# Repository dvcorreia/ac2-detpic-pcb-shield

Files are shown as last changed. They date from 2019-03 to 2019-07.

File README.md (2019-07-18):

<p align="center">This repository contains hardware designs for a PCB shield that extends the detpic32 development board created at DETI UA

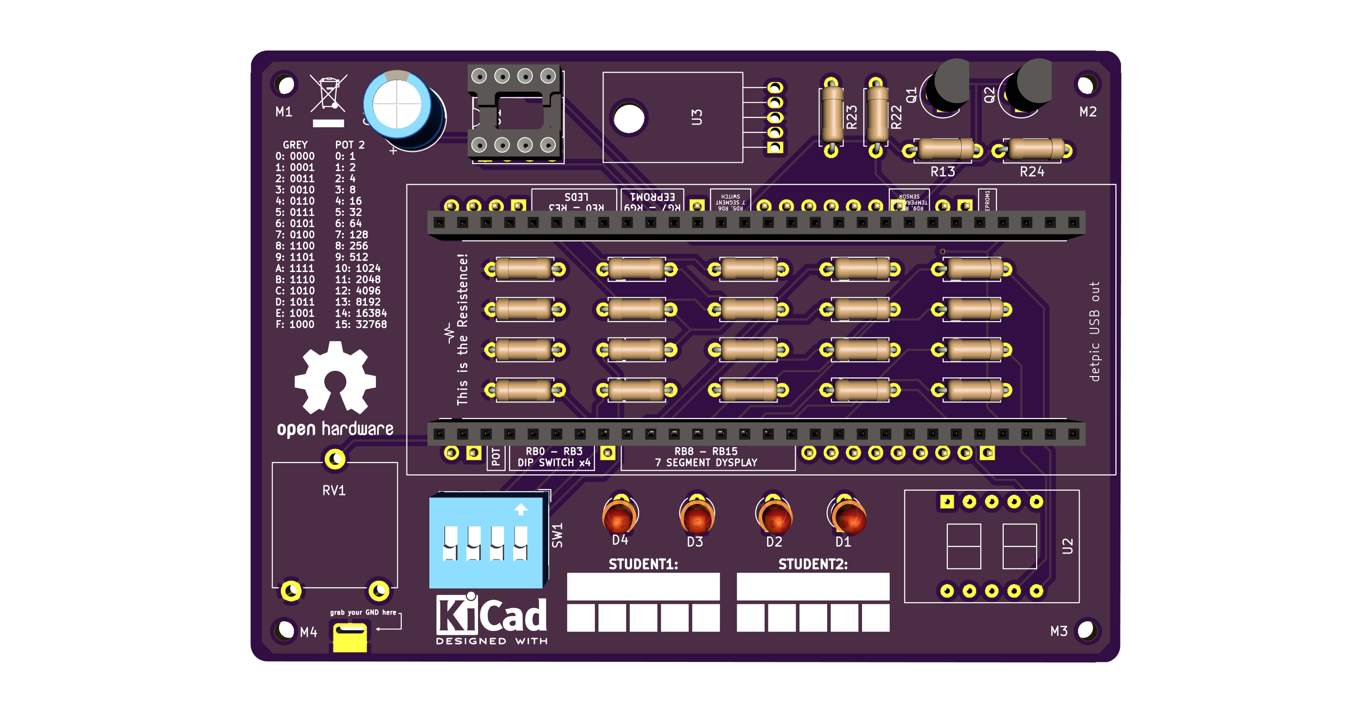
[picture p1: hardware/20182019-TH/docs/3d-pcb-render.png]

</p>

## Description

This project provides a solution to the transportation and handle of the circuitry needed to extend the detpic development board functionalities for the subject of Computer Arquitectures II at Deti UA.

The most frequent situation that the students enrolled in the subject experience is the circuitry assembly in low quality bread boards, usually poorly mounted and disorganized. The transportation inside the backpacks usually causes faulty connections, sometimes hard to debug.

The shield provides a robust solution, easy to transport, user friendly and fault proof.

There are also cases for some of the PCBs that you can 3D print and use! Check inside the PCB folder for the `./cases` directory.

> __The existence of this pcb doesn't imply that the students shouldn't prototype the circuitry in the bread board at least once. It is important that the student understands the schematic and be able to assembly the circuit autonomously.__

## Customize

Most likely you will have to change the PCB, since you might not have some of the components or you have to add a few more. We can't (shouldn't) do it for you, so you have to learn how to work with [Kicad](http://kicad-pcb.org/). Kicad is an open-source PCB designer with builds for every platform. You can read the documentation and there are plenty of tutorials on Youtube.

This is an open source project, so feel free to change the board to your preferences, e.g. add more LEDs, put your name in the PCB, change the components to your needs, etc.

Every PCB in this repo has a README that can be found in the root directory of the respective project folder. This document has useful information that should be read if you plan to modify it.

## Order

Before you order, print the gerber in a sheet of paper and test fit with your components. Boards might have errors or incompatibilities.

The suggested PCB prototype manufacturer is [JLCPCB](https://jlcpcb.com/). It is cheap, less that 10€ for 5 PCBs (< 100x100mm), and you can order it with other students. We have used it before and the quality is ok. Feel free to DIY.

To order you just need to upload the gerber files and follow the instructions in the respective manufacturer website. The gerber files can be found in the gerber folder inside the board project directory.

## Boards

| Name | Descripion | Tested |
|---|---|---|
| [__20182019-TH-V1.1__](https://github.com/dvcorreia/ac2-detpic-shield/tree/master/hardware/20182019-TH) | 1st version of the through hole 2019's board | :red_circle: |

## Issues

Any issue or question can be reported here on Github on the [issues](https://github.com/dvcorreia/ac2-detpic-shield/issues) tab. Remember to describe the problem clearly, write the process so we can emulate the problem. Print-screens might be useful to.
We will try to answer you as fast as possible.

## Contributing

Feel free to contribute your version of the PCB! Others might enjoy it and would like to use it.

To do so, open a [pull request](https://help.github.com/en/articles/about-pull-requests). Make sure to follow the organization structure
already implemented. Don't forget to add a README with useful information. Check the one in _20182019-TH_ project directory has an example.

## License & Copyright

This program is free software: you can redistribute it and/or modify
it under the terms of the GNU General Public License as published by
the Free Software Foundation, either version 3 of the License, or
(at your option) any later version.

This program is distributed in the hope that it will be useful,
but WITHOUT ANY WARRANTY; without even the implied warranty of
MERCHANTABILITY or FITNESS FOR A PARTICULAR PURPOSE.  See the
GNU General Public License for more details.

You should have received a copy of the GNU General Public License
along with this program.  If not, see <https://www.gnu.org/licenses/>.

_Copyright 2019 Diogo Correia_

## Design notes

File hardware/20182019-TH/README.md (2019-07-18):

# 20182019-TH-V1.0

    Name: 20182019-TH-V1.1
    Year: 2018/2019
    Size: 99.06mm x 69.6mm
    Author: Diogo Correia (@dvcorreia)

## Render

Make sure that your components footprints are the ones been used in this PCB. If not be sure to change them.
There is a __test-fit.pdf__ inside the /docs folder that you can print to check if your components fit.

<p align="center">

</p>

## Description

- This board implements the default circuitry of the 2018/2019 subject guide
- All of its components are through hole 
- The routes were computed using [Freerouting](https://freerouting.org/freerouting/using-with-kicad)

## Suggestions

- Replace some through hole components with SMD
- Use resistor arrays

## Pins

| N  | CN1  | Description | CN2  | Description |
|----|---|---|---|---|
| 1  | RE7  | - | RB6  | - |
| 2  | RE6  | - | RB5  | - |
| 3  | RE5  | - | RB4  | Potentiometer |
| 4  | RE4  | - | RB3  | DIP Switch x4 |
| 5  | RE3  | LEDS | RB2  | DIP Switch x4 |
| 6  | RE2  | LEDS | RB1  | DIP Switch x4 |
| 7  | RE1  | LEDS | RB0  | DIP Switch x4 |
| 8  | RE0  | LEDS | RB7  | - |
| 9  | RG7  | EEPROM 1 | RB8  | 7 SEG Display |
| 10 | RG8  | EEPROM 1 | RB9  | 7 SEG Display |
| 11 | RG9  | EEPROM 1 | RB10 | 7 SEG Display |
| 12 | RD7  | - | RB11 | 7 SEG Display |
| 13 | RD6  | 7 SEG Display Switch | RB12 | 7 SEG Display |
| 14 | RD5  | 7 SEG Display Switch | RB13 | 7 SEG Display |
| 15 | RD4  | - | RB14 | 7 SEG Display |
| 16 | RD3  | - | RB15 | 7 SEG Display |
| 17 | RD2  | - | RF0  | - |
| 18 | RD1  | - | RF1  | - |
| 19 | RD0  | - | RF3  | - |
| 20 | RD11 | - | RF4  | - |
| 21 | RD10 | Temperature Sensor | RF5  | - |
| 22 | RD9  | Temperature Sensor | VBUS | - |
| 23 | RD8  | - | VUSB | - |
| 24 | RG3  | - | RG2  | - |
| 25 | RG6  | EEPROM 1 | RC13 | - |

## Cases

| Name | Description | Render Link | Files |
|---|---|---|---|
| case-with-cover | Case with sliding cover | [link](./cases/case-with-cover/renders) | [here](./cases/case-with-cover) |
| stand | Adapted stand from the case-with-cover | [link](./cases/stand/renders) | [here](./cases/stand) |

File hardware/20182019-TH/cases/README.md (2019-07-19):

# Initial commit: 18/07/2019

This files are the .STL objects for a box and a stand designed to accomodate the detpic board.
The stand is a simplistic, earlier version of the box.
The box first version is designed without taking in consideration a large pic on top.
First version is not tested yet.

# Update: 19/07/2019

Organization of different objects through folders:

## case-full
- Box.stl: Main box with updated height for detpic and USB hole.
- Cover.stl: Box cover with slide system.

## case-slim
- Box.stl: The same as case-full/Box.stl but with several holes through the walls in order to save printing material.
- Cover.stl: The same as case-full/Cover.stl but with several holes through the walls in order to save printing material.

### Note: Not 3d Printed or tested yet.

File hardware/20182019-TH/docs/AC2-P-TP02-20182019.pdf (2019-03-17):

Arquitetura de Computadores II, DETI/UA – 2018/19 | 1

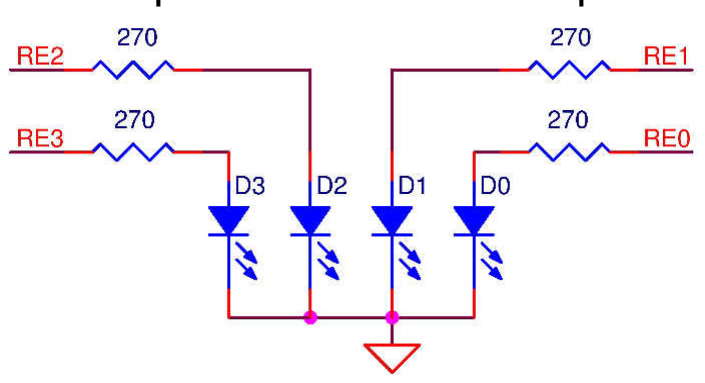
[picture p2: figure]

José Luís Azevedo, Arnaldo Oliveira, Tomás Oliveira e Silva, Pedro Lavrador

### Trabalho prático N.º 2

Objetivos
- Montar, em placa branca, dispositivos simples de interação com o utilizador ligados a portos de I/O do PIC32: 4 LEDs, 1 dip-switch de 4 posições, 2 displays de 7 segmentos e 1 potenciómetro.
- Executar programas de teste fornecidos para verificar o bom funcionamento dos dispositivos montados.
- Utilizar o core timer do MIPS para gerar atrasos programáveis.
Trabalho a realizar
Parte I
1. A Figura 1 apresenta a ligação de 4 LEDs a 4 portos do PIC32 (Porto E: RE0, RE1, RE2 e RE3). Cada LED tem uma resistência em série que limita o valor da corrente que o atravessa. Para a polarização de um LED deste tipo, devemos usar um valor de corrente inferior a 10mA. O valor da corrente no LED é dado por (3.3–1.5)/R, em que 3.3V é o valor da tensão correspondente ao nível lógico '1' no porto e 1.5V é o valor aproximado da tensão aos terminais do LED quando este está no estado ON. Para uma resistência de 270Ω, a corrente é, aproximadamente, 6.7mA.
a) Observe a sugestão de colocação dos componentes na placa branca fornecida na Figura 5 e a disposição dos portos na placa DETPIC32 fornecida na Figura 6 (em anexo). De seguida, monte na placa branca os componentes do esquema da Figura 1.

Figura 1. Ligação de 4 LEDs a portos do PIC32.

b) Transfira para a placa DETPIC32 o programa de teste "test_leds.hex" disponível no moodle da UC. Deverá observar a ativação sequencial dos LEDs, do menos significativo (ligado ao porto RE0), para o mais significativo (ligado ao porto RE3). Se tal não acontecer, verifique a origem do erro e faça as correções devidas.
2. A Figura 2 apresenta o esquema de ligação de um dip-switch de 4 posições a portos do PIC32 (Porto B: RB0, RB1, RB2 e RB3). Em cada um dos portos, a resistência de 10kΩ destina-se a fixar a tensão a zero quando o switch está aberto. A resistência de 470Ω foi incluída para evitar uma possível destruição do porto do microcontrolador no caso de ser configurado, por engano, como uma saída.
a) Monte na placa branca os componentes do esquema da Figura 2.
b) Transfira para a placa DETPIC32 o programa de teste "test_dsw.hex". Com este programa de teste cada um dos switches deverá ativar um LED: SW1 ativa o LED ligado ao porto RE0,…, SW4 ativa o LED ligado ao porto RE3.

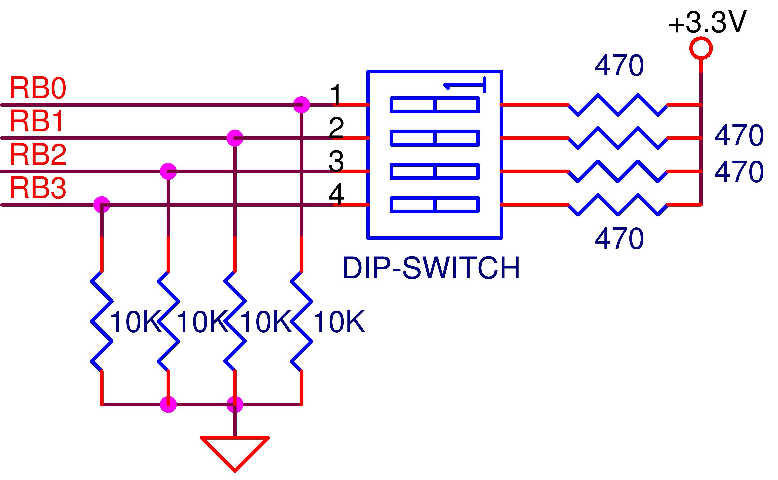
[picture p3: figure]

Figura 2. Ligação de um dip-switch de 4 posições a portos do PIC32.

3. A Figura 3 apresenta o esquema elétrico de ligação de dois displays de 7 segmentos a portos do PIC32 (Porto B: RB8 a RB15; Porto D: RD5 e RD6). Cada um dos displays pode ser ativado ou desativado através dos transístores Q1 e Q2 ligados aos portos RD5 e RD6, respetivamente. Com esta configuração, os displays funcionam em modo alternado, uma vez que o barramento de dados é comum aos dois.
Cada LED do display de 7 segmentos tem em série uma resistência que limita a corrente que nele circula (como já referido no ponto 1); a não colocação desta resistência tem como consequência a destruição do LED e/ou da saída do microcontrolador à qual o LED estiver ligado. A corrente consumida por cada LED pode ser calculada como: I=(3.3–1.5)/R; para uma resistência de 330Ω, a corrente é, aproximadamente, 5.5mA.

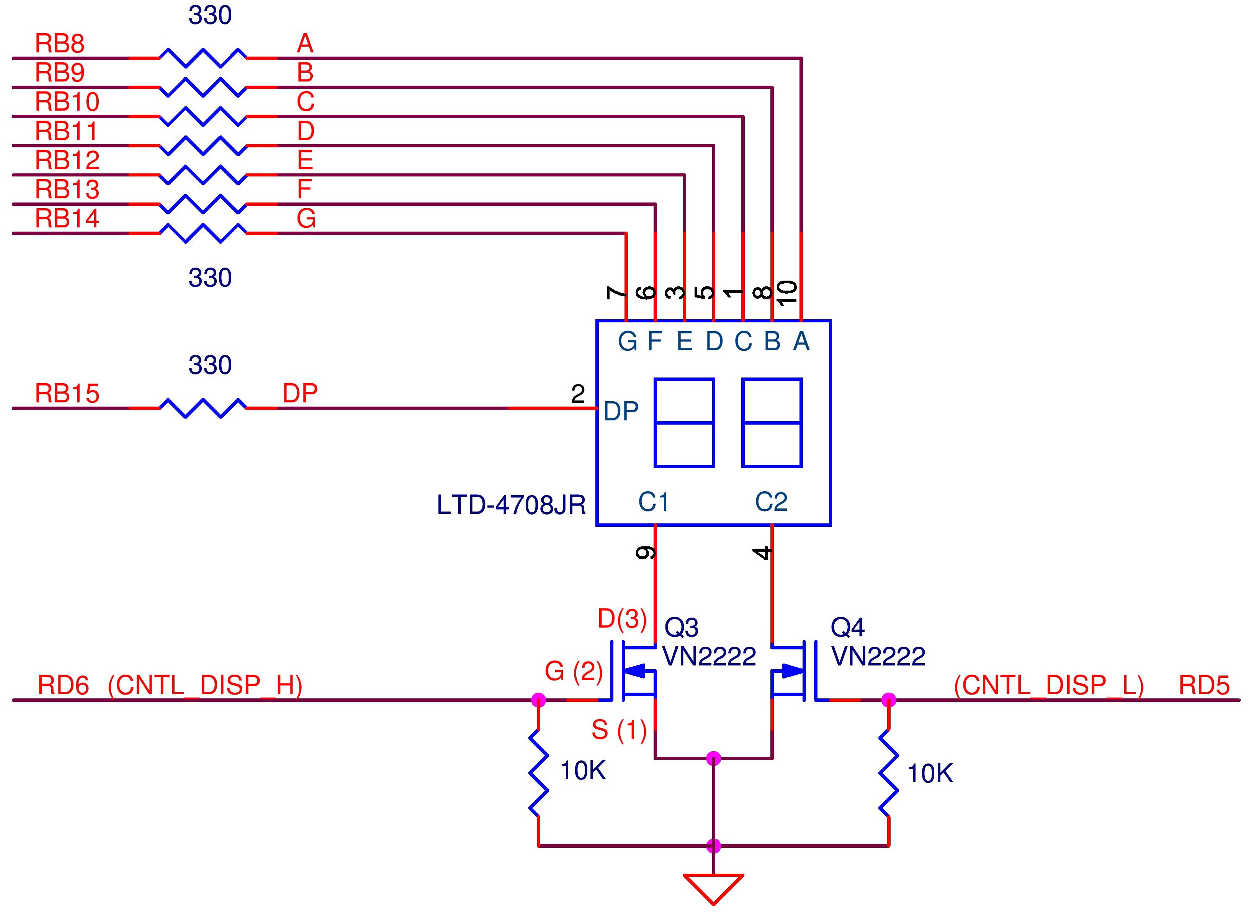
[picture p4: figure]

Figura 3. Ligação de dois displays de 7 segmentos ao porto B do PIC32.

a) Monte os 2 displays de 7 segmentos e os dois transístores, de acordo com o esquema da Figura 3. Verifique no datasheet do display de 7 segmentos (disponível no moodle da UC) qual a correspondência entre cada segmento e o respetivo pino físico.
b) Ligue os dois transístores ao circuito. Verifique previamente quais os pinos físicos correspondentes à gate (G), drain (D) e source (S) (note que a montagem incorreta deste componente impede, ou limita, o bom funcionamento do circuito de visualização).
c) Transfira para a placa DETPIC32 o programa de teste "test_displays.hex". Com este programa deverá observar a ativação sequencial dos LEDs de cada display, do segmento "a" até ao segmento "g", seguida de uma contagem de 0 a F.

4. No circuito da figura seguinte uma resistência variável (designada por potenciómetro) está ligada ao bit AN4 do PIC32 (RB4). Na configuração em que está montada, a resistência variável permite variar, de forma linear, a tensão no seu ponto intermédio entre 0 V e 3.3 V.
a) Monte esse circuito e ligue o ponto intermédio do potenciómetro à entrada RB4 da placa DETPIC32.

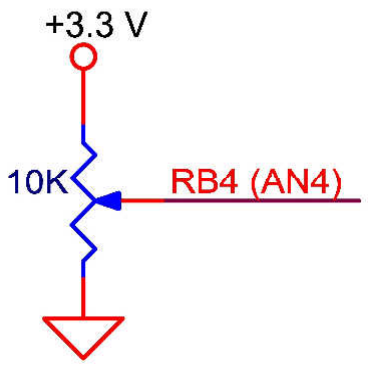
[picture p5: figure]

Figura 4. Ligação de uma resistência variável à placa DETPIC32.

b) Transfira para a placa DETPIC32 o programa de teste "test_all.hex". Com este programa de teste poderá verificar se todo o hardware da placa está a funcionar corretamente. Deverá observar que: i) com todos os switches na posição OFF nos displays deverá aparecer um valor entre 0.0 e 3.3 correspondente ao valor da tensão no potenciómetro e nos LEDs uma indicação da amplitude dessa tensão ii) nas restantes combinações dos switches, os LEDs acendem sequencialmente e os displays mostram o valor hexadecimal da combinação binária presente nos switches.
Parte II
O core MIPS disponível no microcontrolador PIC32 implementa, no coprocessador 0, um contador crescente de 32 bits (designado por core timer) atualizado a cada dois ciclos de relógio do CPU. Na placa DETPIC32 o relógio do CPU está configurado a 40 MHz, pelo que o contador é incrementado a uma frequência de relógio de 20 MHz. Isto significa que o tempo necessário para incrementar o contador desde o valor 0 até 20.000.000 é 1 segundo.
A placa DETPIC32 disponibiliza dois system calls para interagir com esse contador: ler o valor atual do contador (readCoreTimer()) e reiniciar a zero o seu valor (resetCoreTimer()).
1. O programa seguinte incrementa o valor de uma variável à frequência de 100 Hz. De cada vez que a variável é atualizada, o seu valor é apresentado no ecrã do PC.

void main(void)
{
int counter = 0;
while(1)
{
while(readCoreTimer() < 200000); resetCoreTimer();
printInt(++counter, 10);
putChar(' '); // space
}
}
a) Complete a tradução para código assembly do MIPS que se apresenta de seguida e teste-o na placa DETPIC32.
.equ | READ_CORE_TIMER,11
.equ | RESET_CORE_TIMER,?
.equ | PUT_CHAR,?
.equ | PRINT_INT,?

.data
.text
.globl main
main: | li | $t0,0
while: li | $v0,READ_CORE_TIMER # while (1) {
syscall | #
b?? | $v0,200000,??? | # while(readCoreTimer() < 20000);
li | $v0,??? | #
syscall | # resetCoreTimer();
li | $a0,' ' | #
li | $v0,PUT_CHAR | #
syscall | # putChar(' ');
addi | $t0,$t0,??? | #
move | $a0,$t0 | #
li | $a1,10 | #
li | $v0,??? | #
syscall | # printInt(++counter, 10);
? | ??? | # }
jr | $ra | #
b) Altere o código de forma a que a variável seja incrementada com uma frequência de 10 Hz, 5 HZ e de 1Hz.
2. O objetivo da função delay(), apresentada a seguir, é gerar um atraso temporal programável múltiplo de 1ms.
void delay(int ms)
{
for(; ms > 0; ms--)
{
resetCoreTimer();
while(readCoreTimer() < K); }
}
a) Determine o valor da constante K, de modo a que para "ms" igual a 1 o atraso gerado seja 1ms.
b) Traduza para assembly do MIPS a função delay() e teste-a com diferentes valores de entrada (para o teste utilize como base o código C fornecido no ponto 1).
3. Usando a sequência de instruções assembly "lui $t1,0xBF88", "lw $t2,0x6050($t1)" pode ler o valor binário dos 4 switches que montou na sua placa. Esse valor fica disponível nos bits 3 a 0 do registo $t2.
a) Escreva um programa em assembly que leia, com uma frequência de 2 Hz, o valor lógico imposto pelos switches e que o mostre, em binário¹
, no ecrã do PC.
b) Altere o programa anterior de modo a que o valor dos switches seja usado para impor a frequência de leitura, entre 1 Hz e 16 Hz; a constante de tempo para a função delay() pode ser calculada como: k=1000/(valSwitch + 1).
Elementos de apoio
- Datasheets do display LTD-4708JR e do transístor VN2222 (disponíveis no moodle de AC2).

1

O system call printInt permite especificar o número mínimo de dígitos com que o valor é impresso. Essa configuração é feita nos 16 bits mais significativos do registo usado para a base da representação (e.g., para a impressão em binário com 4 bits, o valor a colocar no registo $a1 é 0x00040002).

### Anexo

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
VN2222

DIP

switch

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
DETPIC32

USB

Pino 31 RB6
da placa
branca

+ 3.3 V GND

Resistências de 10 KΩ

Resistências de 470 Ω

Resistências de 270 Ω
Resistências de 330 Ω | Potenciómetro 10KΩ LED D0
| LED D3

Resistências de 10 kΩ

Figura 5. Sugestão de organização do espaço nas placas brancas.

Notas:
1. Não deve utilizar qualquer fonte de tensão externa. Deve-se ter, no entanto, em atenção que o consumo máximo admissível do conjunto não deverá exceder 100 mA.
2. Utilize apenas um barramento da placa branca para a ligação da massa (GND) e apenas um para a ligação da tensão positiva (+3.3V).
3. A inserção/remoção da placa DETPIC32 na placa branca deve ser realizada com muito cuidado de forma a evitar o empeno e consequente quebra dos seus pinos. A inserção deve ser feita pressionando lentamente a placa em ambas as extremidades A remoção deve ser evitada, mas sempre que houver necessidade de o fazer, deverá ser efetuada de forma a puxar simultaneamente as duas extremidades da placa DETPIC32.
4. A placa DETPIC32 deverá ser montada de tal forma que a ficha de ligação USB fique posicionada na extremidade da placa branca. Por outro lado, a ligação à placa DETPIC32 estará menos sujeita a erros se o pino 1 (correspondente ao porto RB6) ficar posicionado no pino 31 da placa branca. Deste modo, para se obter o número do pino da placa DETPIC32 basta subtrair 30 ao número da pista correspondente da placa branca.

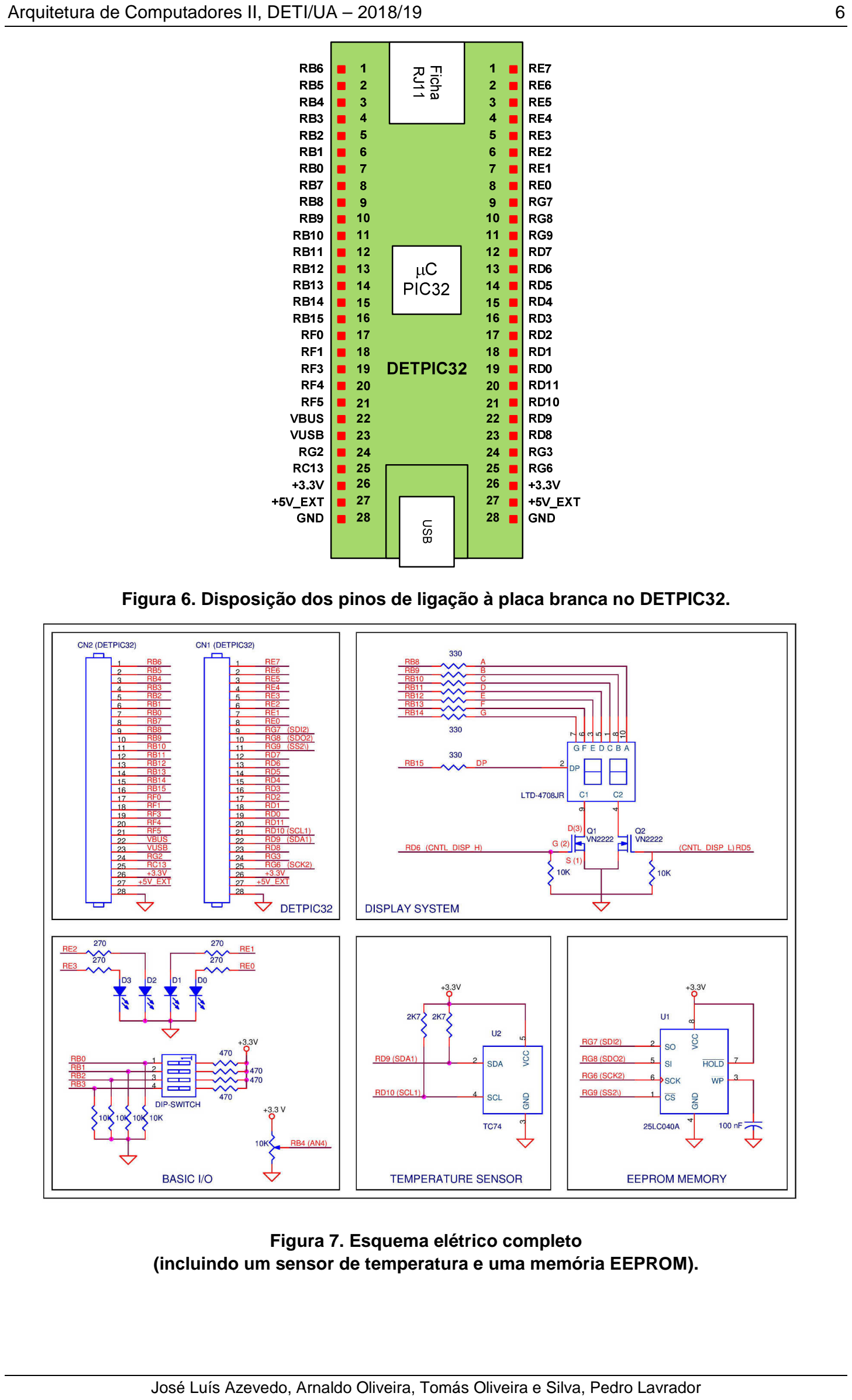
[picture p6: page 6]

Figura 6. Disposição dos pinos de ligação à placa branca no DETPIC32.

Figura 7. Esquema elétrico completo (incluindo um sensor de temperatura e uma memória EEPROM).

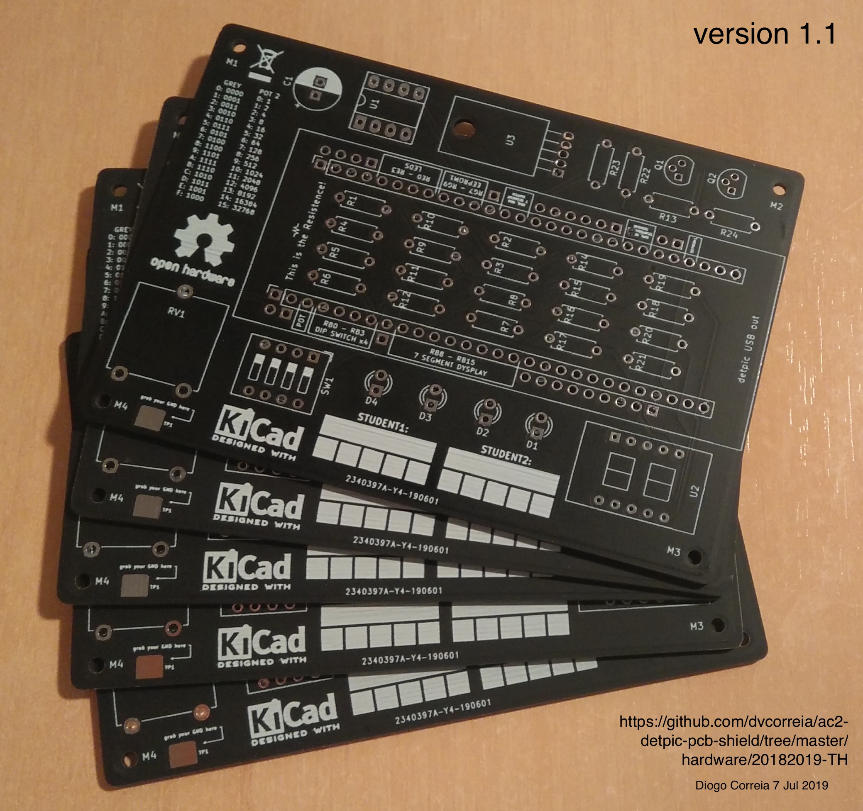
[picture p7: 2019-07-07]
hardware/20182019-TH/docs/photos/20182019-TH-1.1.jpg

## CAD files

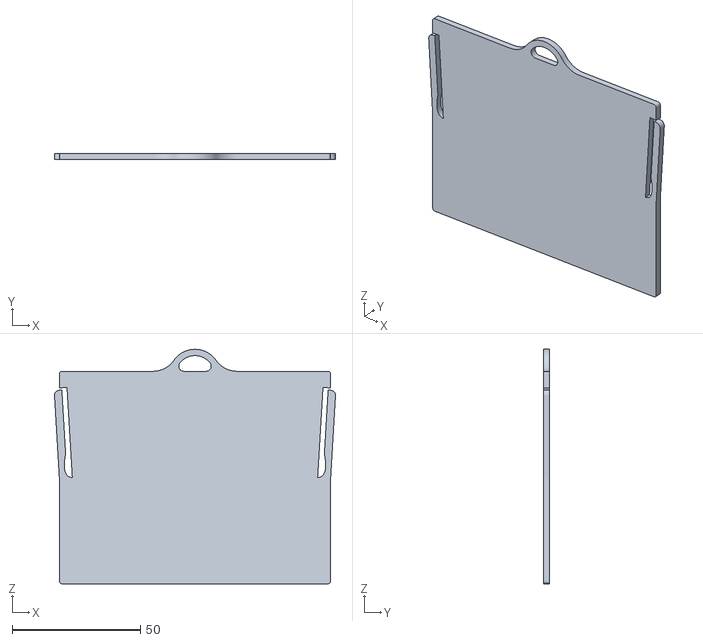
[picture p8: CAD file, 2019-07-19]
hardware/20182019-TH/cases/case-full/Cover.stl
109.8 x 2.50 x 91.6

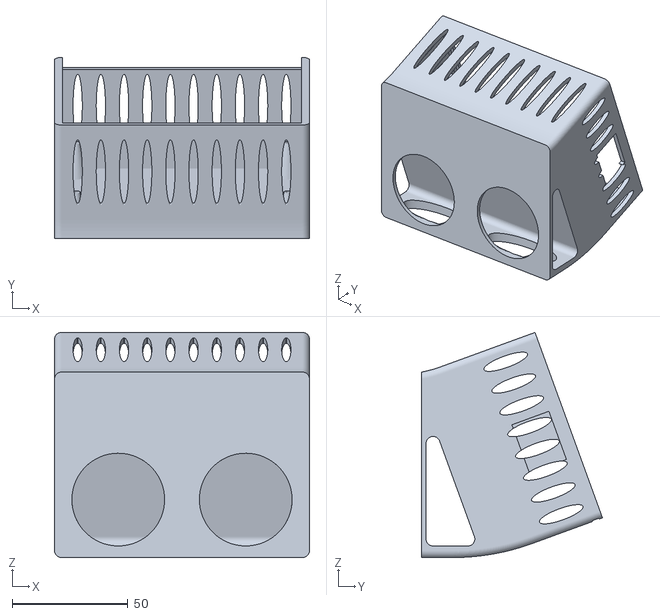
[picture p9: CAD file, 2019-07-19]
hardware/20182019-TH/cases/case-slim/Box.stl
110.0 x 78.1 x 97.1

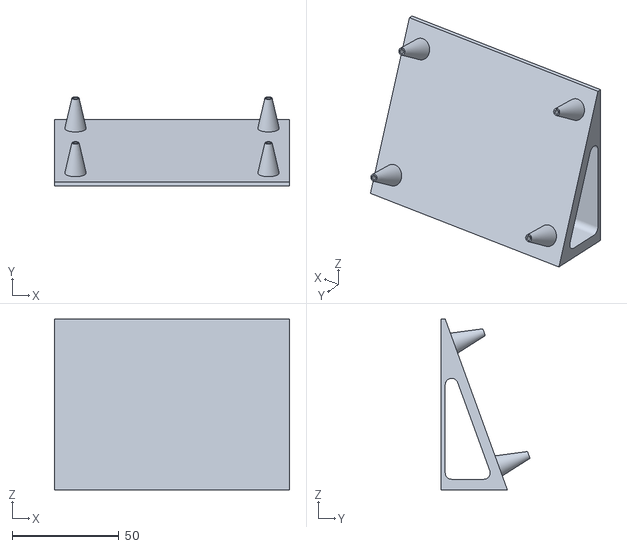
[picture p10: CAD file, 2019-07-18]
hardware/20182019-TH/cases/stand/Stand.stl
110.0 x 41.7 x 80.0

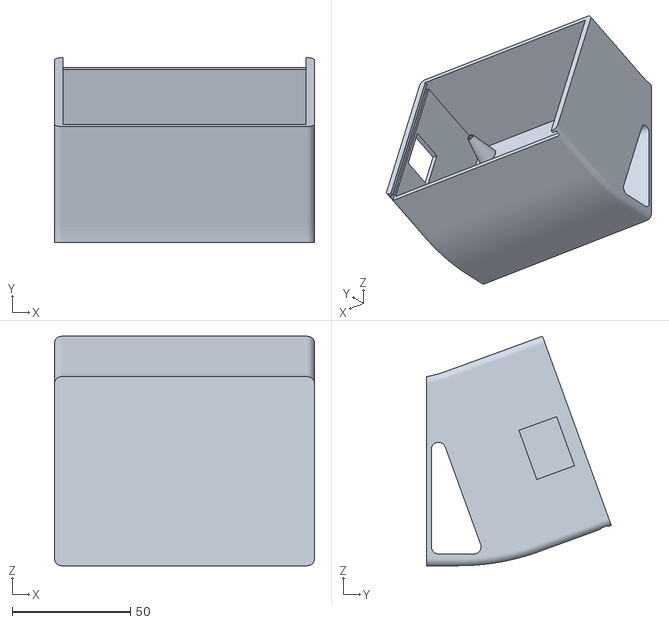
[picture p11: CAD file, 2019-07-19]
hardware/20182019-TH/cases/case-full/Box.stl
110.0 x 78.1 x 97.1

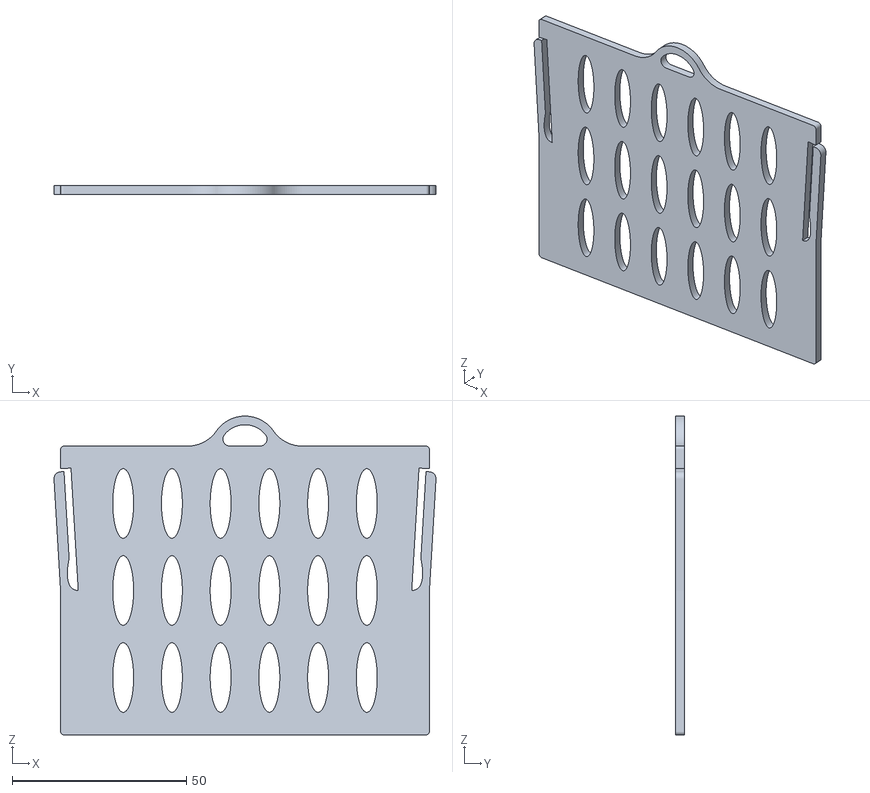
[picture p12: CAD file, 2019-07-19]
hardware/20182019-TH/cases/case-slim/Cover.stl
109.8 x 2.50 x 91.6

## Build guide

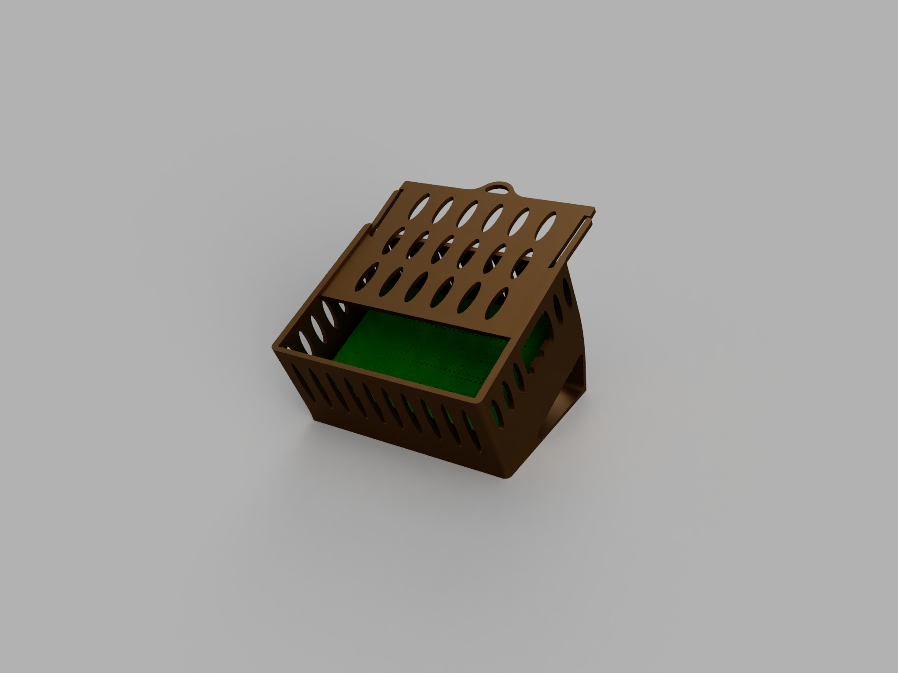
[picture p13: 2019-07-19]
hardware/20182019-TH/cases/case-slim/Assemble.png

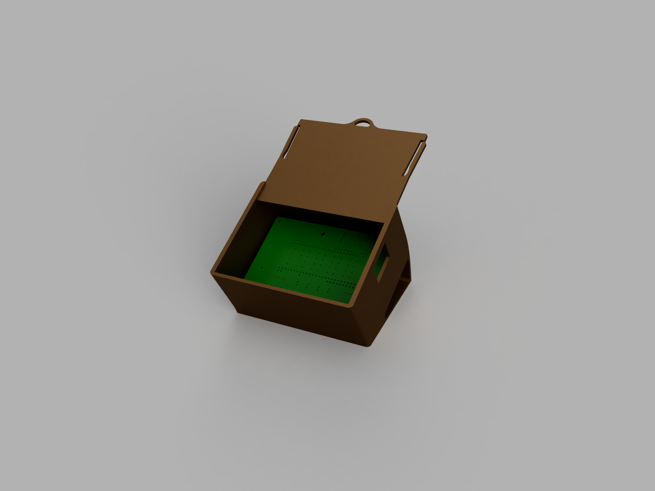
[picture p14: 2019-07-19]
hardware/20182019-TH/cases/case-full/Assemble.png

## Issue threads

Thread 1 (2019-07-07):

Production quality of the 1st batch of 20182019-TH-V1.1

dvcorreia, 2019-07-07:
The first batch of [20182019-TH-V1.1](https://github.com/dvcorreia/ac2-detpic-pcb-shield/tree/master/hardware/20182019-TH) pcbs have arrived. There are some issues that need to be fixed if consistent quality batches from __JLCPCB__ will be commissioned. From first inspection, the following issues are seen:

- some small labels of the PIC pins cannot be read
- "grab your GND here" is not easily visible
- "open hardware" and "design with kicad" seem a bit blurry
- values of the resistors in the silk screen didn't showed up
- via on top of PIC label pins obstructs reading

Image of the pcb with the issues highlighted can be seen bellow:
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

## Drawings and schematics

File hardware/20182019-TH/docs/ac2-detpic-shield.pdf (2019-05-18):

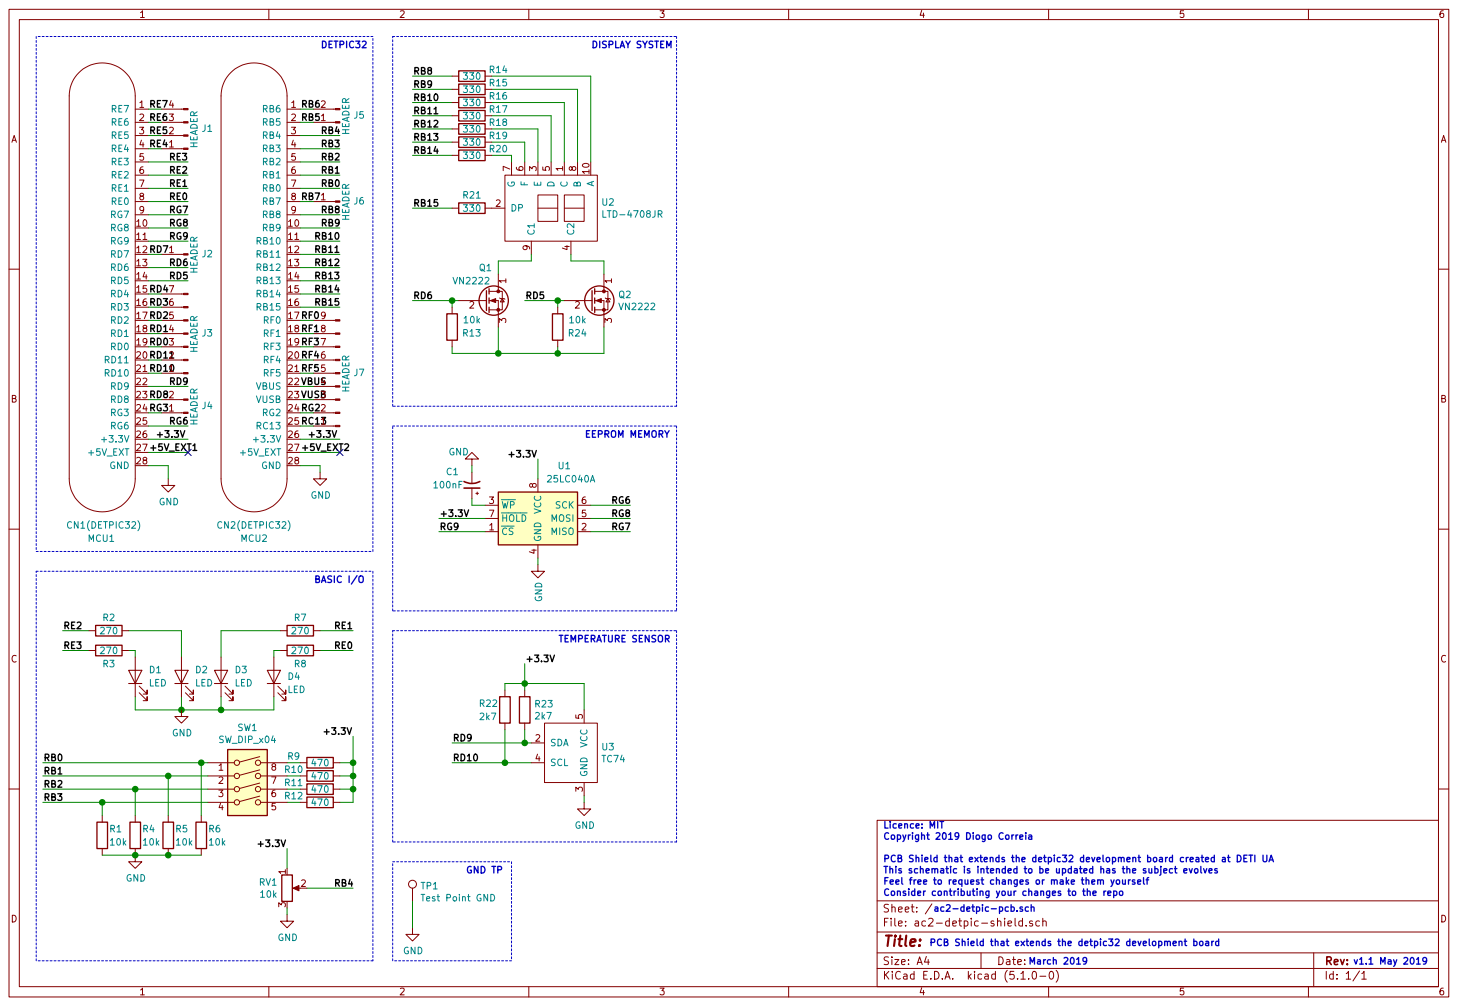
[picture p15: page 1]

File: ac2-detpic-shield.sch Sheet: / Licence: MIT Copyright 2019 Diogo Correia

PCB Shield that extends the detpic32 development board created at DETI UA
This schematic is intended to be updated has the subject evolves
Feel free to request changes or make them yourself
Consider contributing your changes to the repo

PCB Shield that extends the detpic32 development board March 2019

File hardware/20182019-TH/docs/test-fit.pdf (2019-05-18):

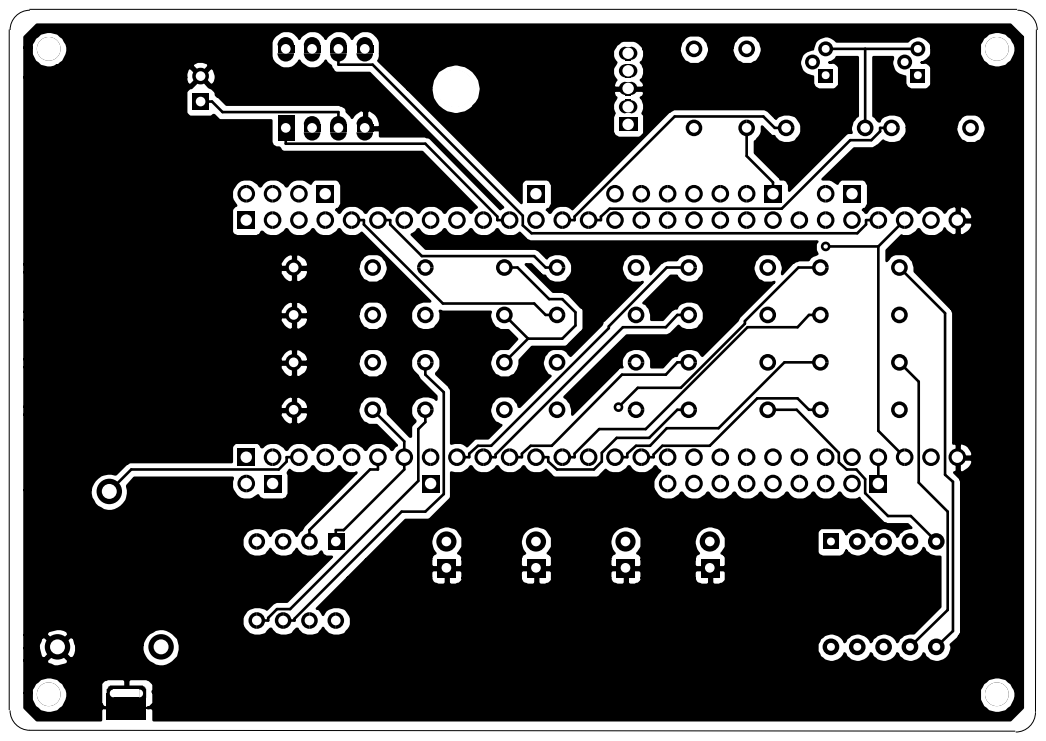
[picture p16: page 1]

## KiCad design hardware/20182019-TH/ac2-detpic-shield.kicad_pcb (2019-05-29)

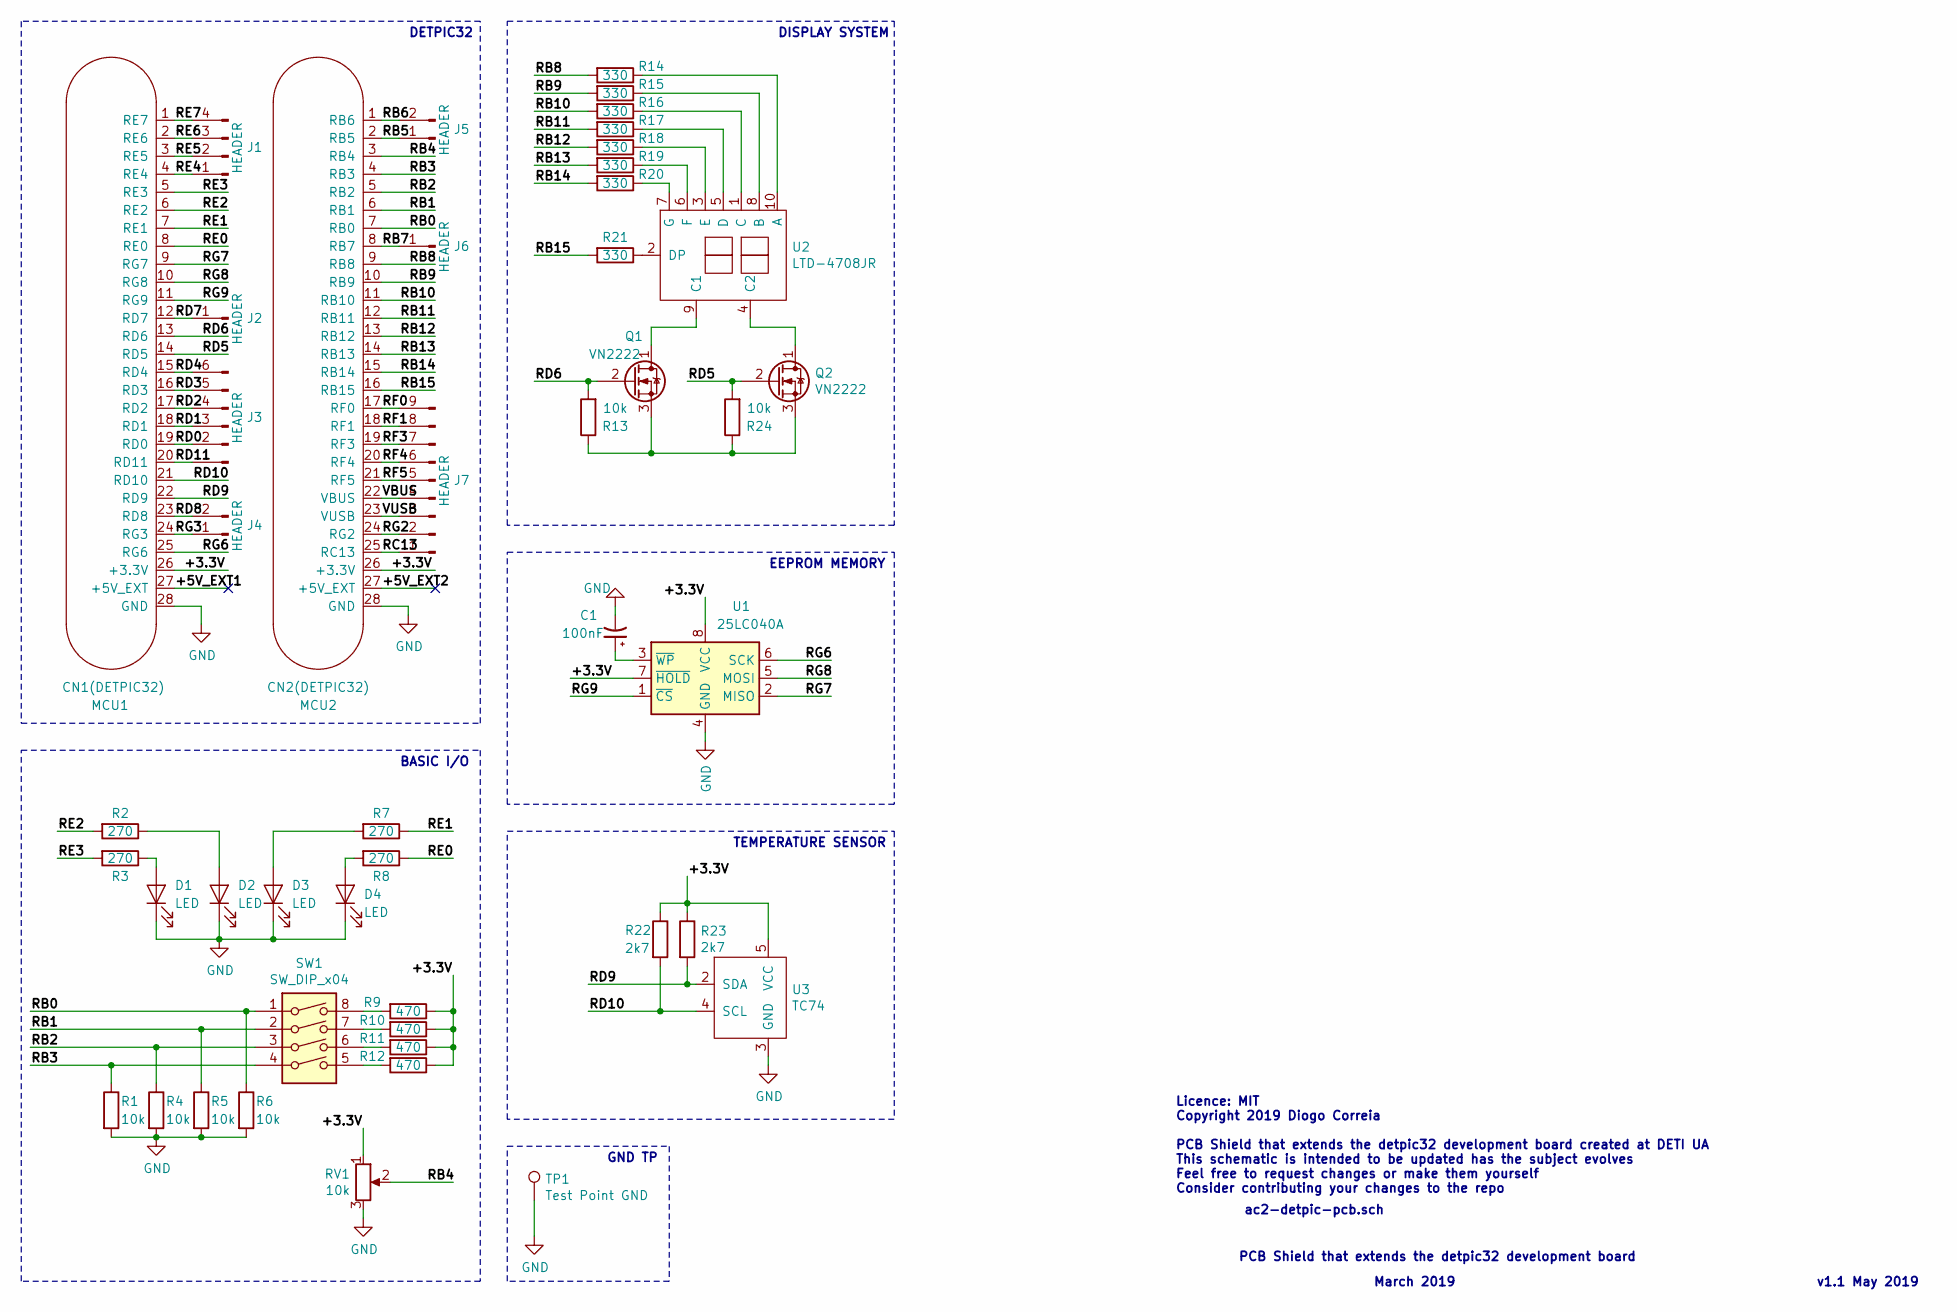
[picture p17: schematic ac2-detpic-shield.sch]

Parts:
C1: 100nF; CP_Radial_D7.5mm_P2.50mm
D1, D2, D3, D4: LED; LED_D3.0mm
J1: HEADER; PinHeader_1x04_P2.54mm_Vertical
J2, J6: HEADER; PinHeader_1x01_P2.54mm_Vertical
J3: HEADER; PinHeader_1x06_P2.54mm_Vertical
J4, J5: HEADER; PinHeader_1x02_P2.54mm_Vertical
J7: HEADER; PinHeader_1x09_P2.54mm_Vertical
MCU1: CN1(DETPIC32); PinSocket_1x28_P2.54mm_Vertical
MCU2: CN2(DETPIC32); PinSocket_1x28_P2.54mm_Vertical
Q1, Q2: VN2222; TO-92
R1, R4, R5, R6, R13, R24: 10k; R_Axial_DIN0207_L6.3mm_D2.5mm_P7.62mm_Horizontal
R2, R3, R7, R8: 270; R_Axial_DIN0207_L6.3mm_D2.5mm_P7.62mm_Horizontal
R9, R10, R11, R12: 470; R_Axial_DIN0207_L6.3mm_D2.5mm_P7.62mm_Horizontal
R14, R15, R16, R17, R18, R19, R20, R21: 330; R_Axial_DIN0207_L6.3mm_D2.5mm_P7.62mm_Horizontal
R22, R23: 2k7; R_Axial_DIN0207_L6.3mm_D2.5mm_P7.62mm_Horizontal
RV1: 10k; Potentiometer_ACP_CA14V-15_Vertical
SW1: SW_DIP_x04; SW_DIP_SPSTx04_Slide_9.78x12.34mm_W7.62mm_P2.54mm
TP1: Test Point GND; TestPoint_Pad_2.5x2.5mm
U1: 25LC040A; DIP-8_W7.62mm_Socket_LongPads
U2: LTD-4708JR
U3: TC74; TO-220-5_Horizontal_TabDown

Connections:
/+3.3V: MCU1.26 (+3.3V), MCU2.26 (+3.3V), R9.1, R10.1, R11.1, R12.1, R22.1, R23.1, RV1.1, U1.7 (~HOLD), U1.8 (VCC), U3.5 (VCC)
/+5V_EXT1: MCU1.27 (+5V_EXT)
/+5V_EXT2: MCU2.27 (+5V_EXT)
/RB0: MCU2.7 (RB0), R6.1, SW1.1
/RB1: MCU2.6 (RB1), R5.1, SW1.2
/RB2: MCU2.5 (RB2), R4.1, SW1.3
/RB3: MCU2.4 (RB3), R1.1, SW1.4
/RB4: MCU2.3 (RB4), RV1.2
/RB5: J5.1, MCU2.2 (RB5)
/RB6: J5.2, MCU2.1 (RB6)
/RB7: J6.1, MCU2.8 (RB7)
/RB8: MCU2.9 (RB8), R14.2
/RB9: MCU2.10 (RB9), R15.2
/RB10: MCU2.11 (RB10), R16.2
/RB11: MCU2.12 (RB11), R17.2
/RB12: MCU2.13 (RB12), R18.2
/RB13: MCU2.14 (RB13), R19.2
/RB14: MCU2.15 (RB14), R20.2
/RB15: MCU2.16 (RB15), R21.2
/RC13: J7.1, MCU2.25 (RC13)
/RD0: J3.2, MCU1.19 (RD0)
/RD1: J3.3, MCU1.18 (RD1)
/RD2: J3.4, MCU1.17 (RD2)
/RD3: J3.5, MCU1.16 (RD3)
/RD4: J3.6, MCU1.15 (RD4)
/RD5: MCU1.14 (RD5), Q2.2 (G), R24.2
/RD6: MCU1.13 (RD6), Q1.2 (G), R13.2
/RD7: J2.1, MCU1.12 (RD7)
/RD8: J4.2, MCU1.23 (RD8)
/RD9: MCU1.22 (RD9), R23.2, U3.2 (SDA)
/RD10: MCU1.21 (RD10), R22.2, U3.4 (SCL)
/RD11: J3.1, MCU1.20 (RD11)
/RE0: MCU1.8 (RE0), R8.1
/RE1: MCU1.7 (RE1), R7.1
/RE2: MCU1.6 (RE2), R2.2
/RE3: MCU1.5 (RE3), R3.2
/RE4: J1.1, MCU1.4 (RE4)
/RE5: J1.2, MCU1.3 (RE5)
/RE6: J1.3, MCU1.2 (RE6)
/RE7: J1.4, MCU1.1 (RE7)
/RF0: J7.9, MCU2.17 (RF0)
/RF1: J7.8, MCU2.18 (RF1)
/RF3: J7.7, MCU2.19 (RF3)
/RF4: J7.6, MCU2.20 (RF4)
/RF5: J7.5, MCU2.21 (RF5)
/RG2: J7.2, MCU2.24 (RG2)
/RG3: J4.1, MCU1.24 (RG3)
/RG6: MCU1.25 (RG6), U1.6 (SCK)
/RG7: MCU1.9 (RG7), U1.2 (MISO)
/RG8: MCU1.10 (RG8), U1.5 (MOSI)
/RG9: MCU1.11 (RG9), U1.1 (~CS)
/VBUS: J7.4, MCU2.22 (VBUS)
/VUSB: J7.3, MCU2.23 (VUSB)
GND: C1.2, D1.1 (K), D2.1 (K), D3.1 (K), D4.1 (K), MCU1.28 (GND), MCU2.28 (GND), R1.2, R4.2, R5.2, R6.2, RV1.3, TP1.1, U1.4 (GND), U3.3 (GND)
unnamed: C1.1, U1.3 (~WP)
unnamed: D1.2 (A), R3.1
unnamed: D2.2 (A), R2.1
unnamed: D3.2 (A), R7.2
unnamed: D4.2 (A), R8.2
unnamed: Q1.1 (D), U2.9 (C1)
unnamed: Q1.3 (S), Q2.3 (S), R13.1, R24.1
unnamed: Q2.1 (D), U2.4 (C2)
unnamed: R9.2, SW1.8
unnamed: R10.2, SW1.7
unnamed: R11.2, SW1.6
unnamed: R12.2, SW1.5
unnamed: R14.1, U2.10 (A)
unnamed: R15.1, U2.8 (B)
unnamed: R16.1, U2.1 (C)
unnamed: R17.1, U2.5 (D)
unnamed: R18.1, U2.3 (E)
unnamed: R19.1, U2.6 (F)
unnamed: R20.1, U2.7 (G)
unnamed: R21.1, U2.2 (DP)

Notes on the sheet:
Licence: MIT Copyright 2019 Diogo Correia PCB Shield that extends the detpic32 development board created at DETI UA This schematic is intended to be updated has the subject evolves Feel free to request changes or make them yourself Consider contributing your changes to the repo
ac2-detpic-pcb.sch
PCB Shield that extends the detpic32 development board
March 2019
DETPIC32
BASIC I/O
DISPLAY SYSTEM
EEPROM MEMORY
TEMPERATURE SENSOR
GND TP
v1.1 May 2019

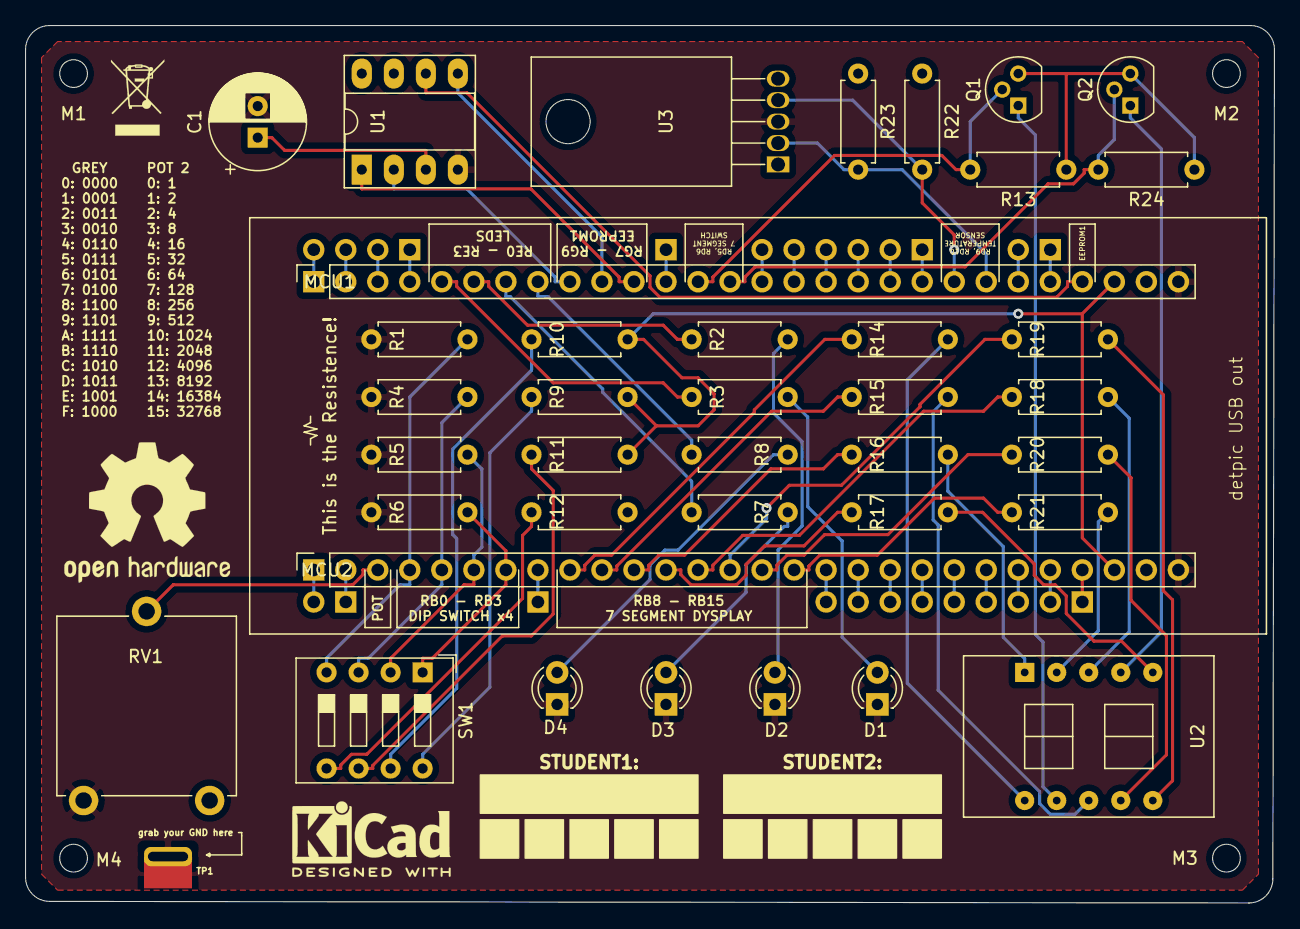
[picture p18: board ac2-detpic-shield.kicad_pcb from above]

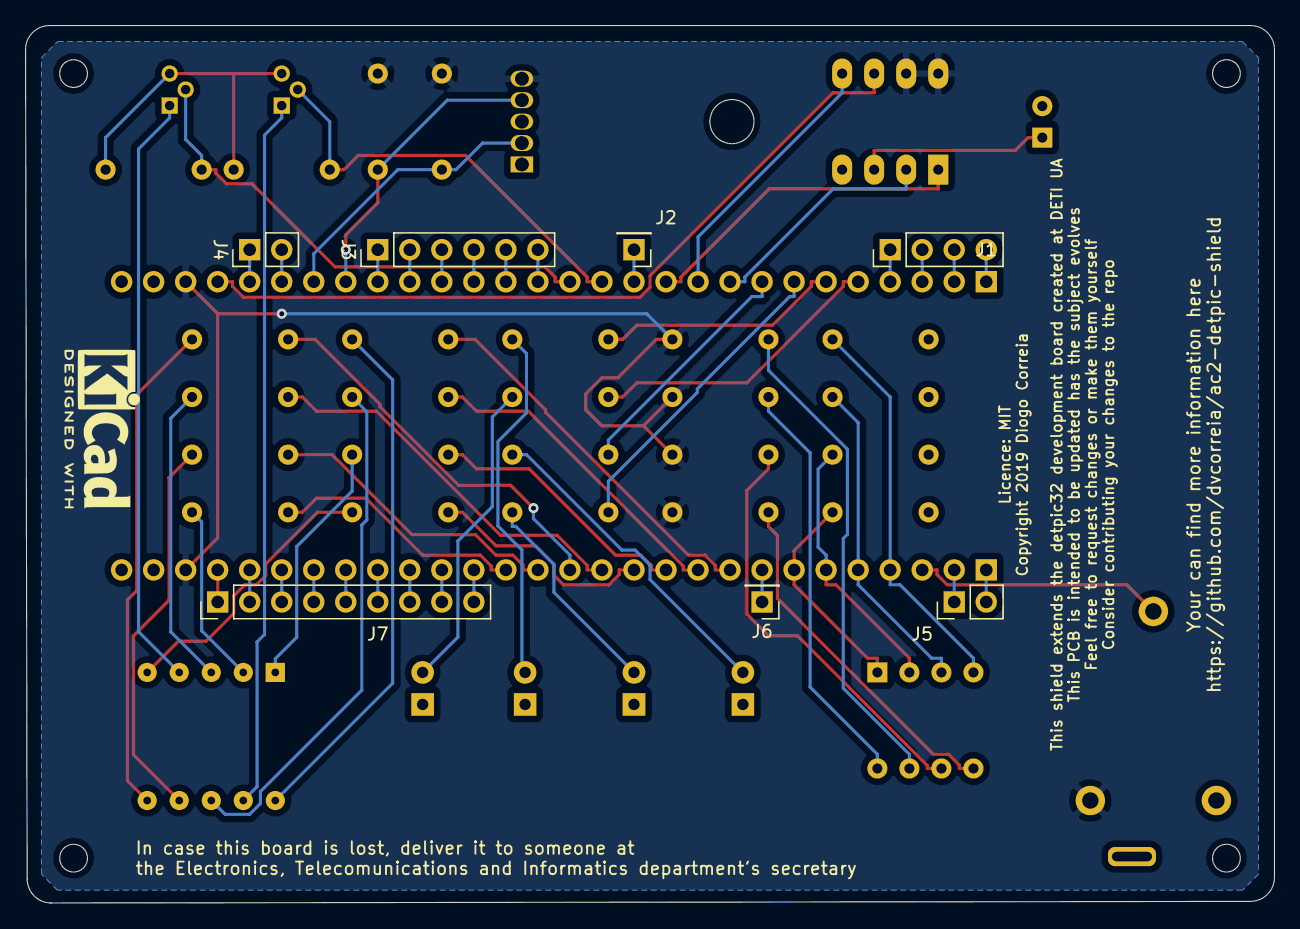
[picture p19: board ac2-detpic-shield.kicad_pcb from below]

Board: 2 copper layers, 99.1 x 69.6 mm, 54 parts (8 on the bottom side), 72 nets.

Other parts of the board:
M1: M1; MountingHole_2.2mm_M2
M2: M2; MountingHole_2.2mm_M2
M3, M4: MountingHole_2.2mm_M2
REF1: WEEE-Logo_4.2x6mm_SilkScreen
REF2: OSHW-Logo2_14.6x12mm_SilkScreen
REF3, REF4: KiCad-Logo2_5mm_SilkScreen

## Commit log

2019-03-17 project started!
    [ac2-detpic-shield.kicad_pcb, ac2-detpic-shield.sch]
2019-03-24 reformulation of library handle
    [ac2-detpic-shield.sch]
2019-03-24 added eeprom module
    [ac2-detpic-shield.sch]
2019-03-24 added temperature sensor module
    [ac2-detpic-shield.sch]
2019-03-25 LTD-4708JR footprint created and footprints assigment completed
    [ac2-detpic-shield.sch]
2019-03-25 file structure in docs changed + pcb layout and detpic aux info done
    [ac2-detpic-shield.kicad_pcb, ac2-detpic-shield.sch]
2019-03-26 pcb completed + gerbers exported
    [ac2-detpic-shield-B_Cu.gbr, ac2-detpic-shield-B_Fab.gbr, ac2-detpic-shield-B_Mask.gbr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]
2019-03-26 folder structure changed to handle more pcbs version + main README done
    [ac2-detpic-shield-B_Cu.gbr, ac2-detpic-shield-B_Fab.gbr, ac2-detpic-shield-B_Mask.gbr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]
2019-03-28 detpic32 size fixed, freeroute files and organization file directory changes
    [ac2-detpic-shield-B_Cu.gbr, ac2-detpic-shield-B_Fab.gbr, ac2-detpic-shield-B_Mask.gbr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]
2019-03-29 added basic documentation to 20182019-TH-V1.0 board
    [ac2-detpic-shield.dsn]
2019-04-15 added license 📄
2019-05-18 added gnd test point to 20182019-TH v1.1
    [ac2-detpic-shield-B_Cu.gbr, ac2-detpic-shield-B_Fab.gbr, ac2-detpic-shield-B_Mask.gbr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]
2019-05-18 changed folder structure
    [ac2-detpic-shield-B_Cu.gbr, ac2-detpic-shield-B_Fab.gbr, ac2-detpic-shield-B_Mask.gbr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]
2019-05-18 arrangement in the M4 label in 20182019-TH board
    [ac2-detpic-shield.kicad_pcb]
2019-05-18 added tested column to boards description
2019-05-29 changed stuff in the back silk
    [ac2-detpic-shield-B_Cu.gbr, ac2-detpic-shield-B_Fab.gbr, ac2-detpic-shield-B_Mask.gbr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]
2019-05-29 fixed bug in J3 header in 20182019-TH pcb
    [ac2-detpic-shield-B_Cu.gbr, ac2-detpic-shield-B_Fab.gbr, ac2-detpic-shield-B_Mask.gbr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]
2019-05-29 changed README.md to clean information in 20182019-TH board
2019-05-29 new gerbers and fix in README.md of the 20192018-TH board
    [ac2-detpic-shield-B_Cu.gbr, ac2-detpic-shield-B_Fab.gbr, ac2-detpic-shield-B_Mask.gbr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]
2019-07-07 added photo of 20182019-TH version 1.1 pcb
2019-07-18 Added Box and Stand
    Added Box (Box.stl) and Box Cover (BoxCover.stl).
    Added simple Stand with 20º inclination (Stand.stl)
    [Box.stl, BoxCover.stl, Stand.stl]
2019-07-18 corrected spelling errors + changed cases organization + added cases docs
    [Stand.stl, box-cover.stl, box.stl]
2019-07-19 Organization in folders; update on objects and creation of slim versions
    [Box.stl, Cover.stl, Stand.stl]
2019-07-19 Removal of old versions
    [Box.stl, BoxCover.stl, Stand.stl]
2019-07-19 Update objects, added slim version
    [Box.stl, Cover.stl, box-cover.stl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]
2019-07-19 remove old version
    [Box.stl, Cover.stl, Stand.stl]
